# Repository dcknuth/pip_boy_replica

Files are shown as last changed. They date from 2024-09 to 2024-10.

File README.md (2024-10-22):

# Pip-Boy Replica
Making a Pip-Boy replica. Will not exactly match any given model from the game or episodes, but is inspired by them

[Video of the final product](https://youtu.be/MKkzPV8Xsxo)
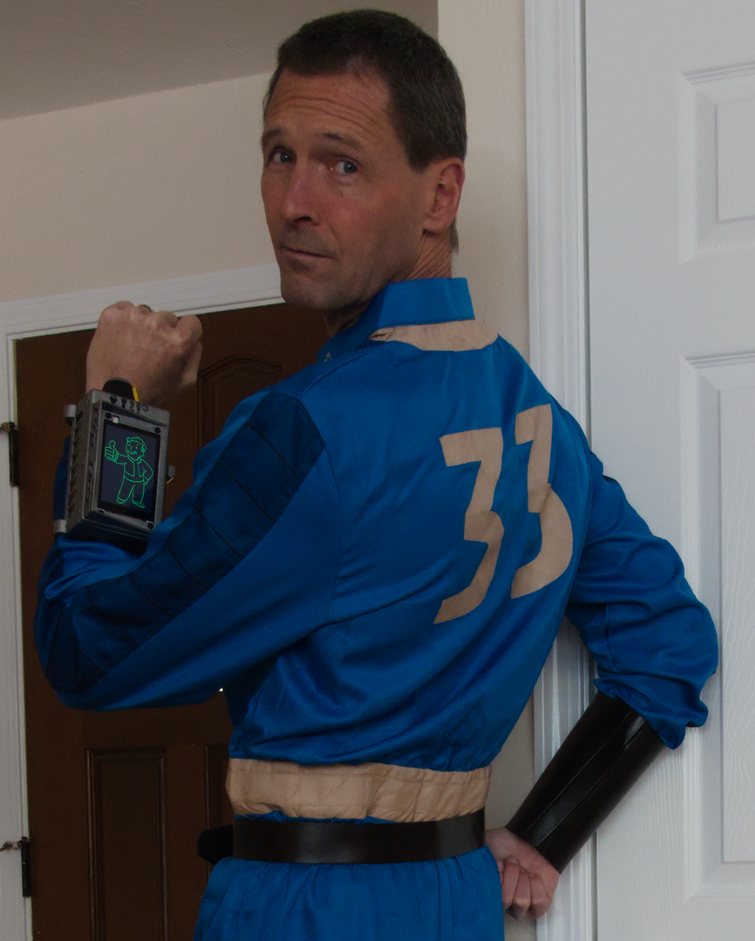
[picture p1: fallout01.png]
Showing Fallout Boy mode

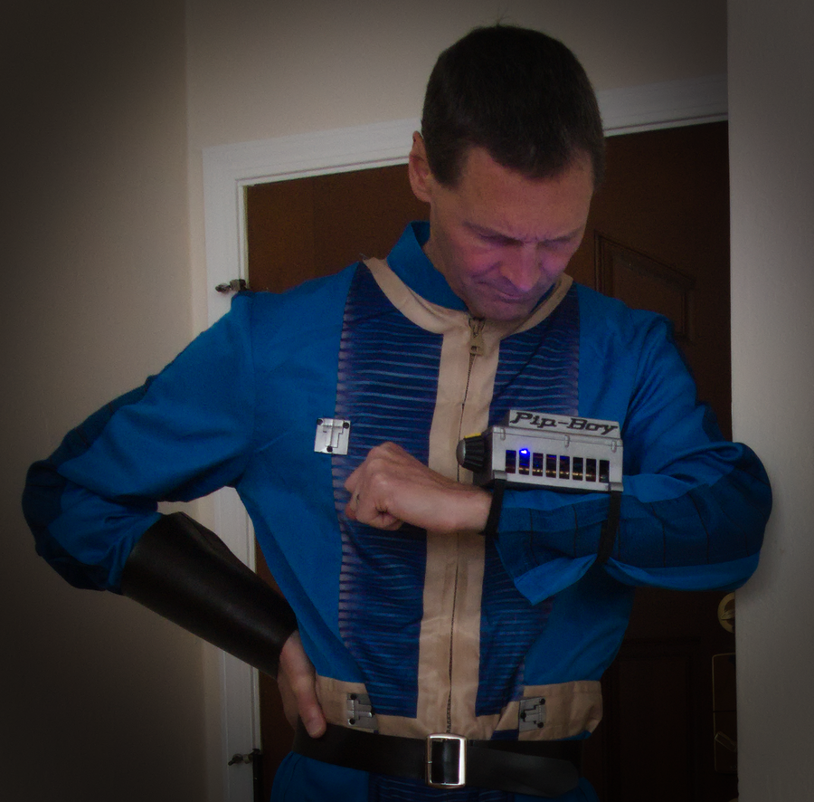
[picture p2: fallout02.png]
View of the front with flashlight mode on

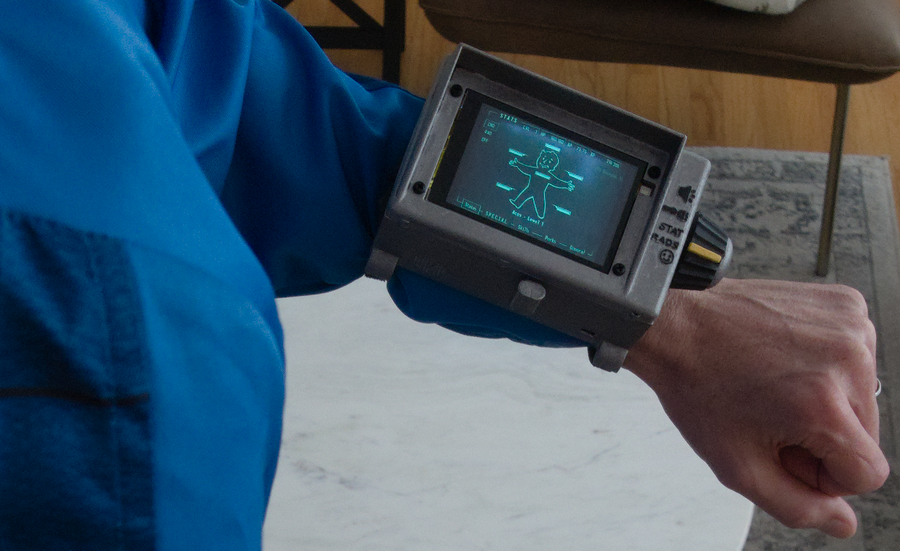
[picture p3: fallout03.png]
View of the top showing status mode


## Function List
These are the functions that we will try to add to our Pip-Boy with a bit of discussion on how and why
* Fallout Boy - Just a picture of the "thumbs up" fallout boy image. Recognizable from a distance and was a big plot item for the Amazon Fallout series in addition to being common in the games
* Geiger Counter - A real, working one based on data passed from a [MightyOhm Geiger Counter DIY kit](https://mightyohm.com/blog/products/geiger-counter/). I think I bought mine through [AdaFruit](https://www.adafruit.com/product/483)
* Status Indicator - Just a static screen borrowed from the Fallout 3 video game
* Flashlight - Will just turn on the screen to white and the front-facing LED of this particular board to ~90%. Might even be useful Halloween night?
* Radio - Will play "I Don't Want to Set the World on Fire", which was the intro song to the Fallout 3 video game and was in the Amazon series. The screen will show a static radio mode image from the game

## The Case
The case is 3D printed and will be in four parts:
* A bottom that the Geiger counter can be screwed into. It will additionally house:
  - Cutouts to the Geiger-Muller tube. For better reading, but mostly so you can just see it's there
  - Power switch for the Geiger counter and one for the screen/system
  - Hole and key for the rotary encoder board
  - Speaker grills for the beeper on the Geiger counter and for the speaker from the main board
  - Hole for a USB-C connector. This will charge the battery, not program the ESP32
  - Holes to hold small magnets to secure the top to the bottom
* A case top with the following:
  - Hole for the screen and LED. Also a recess for the unused ambient light sensor
  - A hood, mostly for aesthetic reasons. It's there in the game and other replicas and will give us a place to put some lettering that is visible
  - Indicator markings for what mode we are in
  - Holes for the small magnets to hold the top and bottom together
* A knob, to select the mode we are in. It will pressure fit to the rotary encoder shaft
* A pocket for the lithium polymer battery. It will be combined with a AAA blank so it can go where a AAA would be placed in the Geiger counter. This should keep it from moving around inside the case and damaging the Geiger tube.

All the OpenSCAD models are in the [3d_models](https://github.com/dcknuth/pip_boy_replica/3d_models) directory. There are a few extras that are needed modules or might be helpful

## Parts List
Will fill this in as the project progresses
* [Display with ESP32 - ESP32-3248S035](https://www.amazon.com/gp/product/B0C4KSKW96)
* [MightyOhm Geiger Counter](https://www.adafruit.com/product/483)
* Small speaker - I salvaged mine from some old device that I no longer remember
* [Rotary encoder](https://www.amazon.com/gp/product/B07B68H6R8) - to switch between modes. A custom knob will go on top of this
* 3D printer, I will not link, but I have an Ender3 that is a couple years old
* I used [this filament](https://www.amazon.com/gp/product/B00MEZEEJ2/), but most PLA should be fine. This is a color that would be forgiving if it shows through
* [Step up and charge controller board](https://www.amazon.com/gp/product/B09YD5C9QC/?th=1) This will get you the 5 volts you need to power the ESP32 board above from the lithium polymer battery below
* [Lipo battery](https://www.amazon.com/gp/product/B098DSP8YC/) Can power both the ESP32 board and the Geiger counter for some time and will still fit inside the case (smaller than the Geiger counter length)
* [Buck down](https://www.amazon.com/gp/product/B07T7L51ZW/) Converter to go from 5v to the 3v the Geiger counter wants
* [Jumper kit](https://www.amazon.com/gp/product/B08RMQP6YP/) To make jumper cables for the power switches and to hook things up in a way that can be disassembled easily
* [4-40 screws](https://www.amazon.com/gp/product/B0BNN7YRX8/) These are a good size to keep the Geiger attached to the bottom of the case with threads that are just big enough to 3D print a female side to the mount pads. I used the shortest 3/16 length
* [USB-C right angle](https://www.amazon.com/gp/product/B0B2NJ3P3L/) This allowed a friction fit to hold the step-up/charger board to the side of the case and to plug/unplug a charging cable without having to stress the PipBoy too much
* Small SD card. Any <= 4G should work. After some trouble that was not the fault of my first card, I bought [these](https://www.amazon.com/gp/product/B0D2SW1BLR/?th=1) They work
* Some [black nylon screws](https://www.amazon.com/gp/product/B0BNB1K5P2/) and nuts to hold the screen to the top part of the box
* Some [super glue](https://www.amazon.com/gp/product/B0041GVBBG/) To glue in the magnets
* I used the smallest of [these magnets](https://www.amazon.com/gp/product/B0CW65QR14/) You can look at the size of the holes that they go in to double check sizing
* I already had some hook and loop cable manager on hand, [like this](https://www.amazon.com/Xnakko-Double-Fastening-Reusable-Manager/dp/B095PNTVJ4/) to go through the lugs at the corners of the lower case and hold it to your forearm
* [This](https://www.amazon.com/gp/product/B07N6HFBRX/) smoothed out the 3D prints with some acetone to dilute it to make it easier to work with
* Then [this](https://www.amazon.com/Rust-Oleum-Automotive-260510-12-Ounce-Sandable/dp/B006ZLQ4HQ/) to prime and finish filling in the parts
* To paint the raised lettering I used [acrylic pens](https://www.amazon.com/gp/product/B0BKP1M6QK/?th=1)
* I borrowed my daughter's acrylic paints and brushes to do non-spray parts (I got her some additional to even things up)
* Most parts were finished with [this pounded pewter spray paint](https://www.homedepot.com/p/BEHR-PREMIUM-12-oz-SP-303-Antique-Pewter-Gloss-Interior-Exterior-Hammered-Spray-Paint-Aerosol-B061344/319367935) I don't know if I super-love this, but it worked
* You will need a variety of sandpaper

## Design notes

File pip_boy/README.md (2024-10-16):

# Platformio Project for Pip-Boy Replica
This is the code part for the ESP32-3248S035 that is the screen of the replica and drives most of the functionality

## Warnings
* TJpg_Decoder cannot handle progressively encoded jpegs. It will find the file, but report 0 width and height and not display
* Some of the options to libraries used seem to have to be passed in as compiler flags to make it to the compiling of the parts of the libraries. This is why there are a bunch of "-D" flags in the platformio.ini file. This can cause confusion with descriptions/instructions using the Arduino IDE which don't seem to need this
* Also a difference, PlatformIO wants proper function declarations or definitions prior to using them, which Arduino often does not need, so I move those up front or declare them as needed

## Overview
There are five modes to the device that are each pretty simple on their own and I use a rotary encoder library to help switch between the modes. Each of the modes might have three pieces:
1. Definitions or declarations in the pip_boy_config.h file or at the top of the main.cpp file. I have tried to keep them all there and this includes functions needed
2. Setup is mostly in the main setup function as it is supposed to be
3. The loop in main is setup to first change between the modes in response to a move of the rotary encoder and then to keep any current background tasks running for the mode in use

The modes are:
### Fallout Boy
This just displays an image of Fallout Boy in Portrait so that if you are holding the PipBoy on the left hand up, he shows in the proper way. All the images come off of the SD card as the modes switches via the TJpg_Decoder library. This image is the only one that needs to be rotated 90 degrees clockwise before being stored to the card
### Geiger Counter
This will display a speedometer-like gauge where the needle should point at the current count from the geiger counter. The geiger counter sends this out over its serial connection every second and we try to pull characters from this one-by-one every time through the event loop. This is done via this EspSoftwareSerial library. When we get to the end of a line, the count for that second is updated and the needle for the gauge is moved when a change in that value is detected. There is a pound define to just keep bouncing the value from 0 to 100 as background radiation seems to average a bit under 1. You have to hold a source very close to the tube to get more than three counts in a second. A log (or adaptive) scale might be better, but is left as an exercise for the reader. The count goes to zero if the geiger counter is starting or something weird happens to the serial line (as a natural part of trying to parse and read the input). This should be fine and things will fix themselves when the updates start or the next line comes in. The updating of the needle is done with the TFT_eSPI library and two sprites.
### Status
Just displays a static, status image from the in-game PipBoy in proper landscape orientation
### Flashlight
Sets the screen to white and turns on the front facing LED at a high brightness. Interesting and the particular board I used had the LED on the front, but probably not great as an actual flashlight. Matches a function of the PipBoy in the games though
### Radio
Displays a static radio image from the games and plays a version of the intro song to Fallout 3 via the ESP8266Audio library

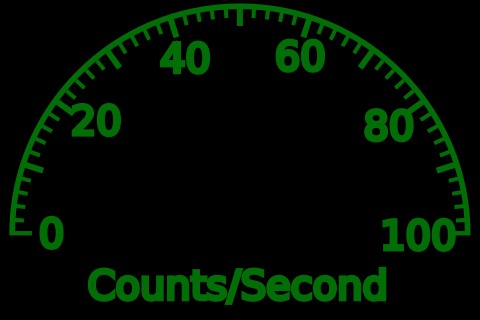
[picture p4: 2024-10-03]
sd_card_images/rads_dial.jpg

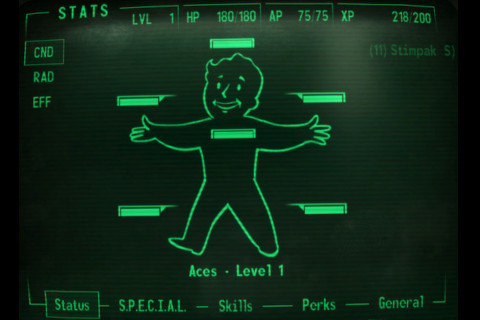
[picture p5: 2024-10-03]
sd_card_images/status_480x320.jpg

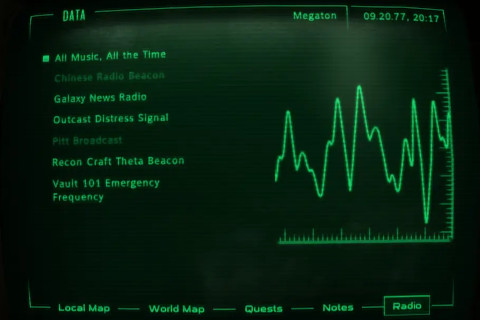
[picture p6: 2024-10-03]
sd_card_images/radio480x320.jpg

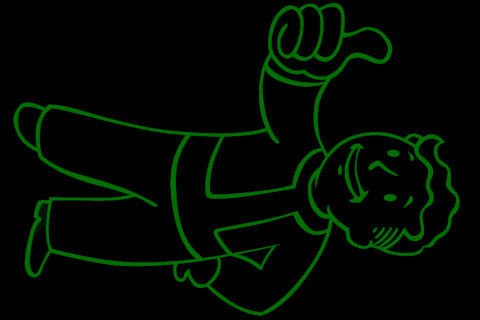
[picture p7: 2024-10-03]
sd_card_images/fallout-boy480x320.jpg

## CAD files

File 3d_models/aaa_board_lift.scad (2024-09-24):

// aaa blank with a handle on it to set a board into a tight box
$fn = 100;
use <aaa_battery.scad>;
body_l = 42.8;
aaa_d = 10.4;
wall = 1.6;

union() {
  aaaBattery(body_l=body_l, pos_button_h=0.8);
  hull() {
    translate([aaa_d/2-wall, 0, wall])
      rotate([90, 0, 0])
        cylinder(h=wall, d=wall, center=true);
    translate([body_l/2.5, 0, body_l/2])
      rotate([90, 0, 0])
        cylinder(h=wall, d=wall, center=true);
    translate([aaa_d/2-wall, 0, body_l-wall])
      rotate([90, 0, 0])
        cylinder(h=wall, d=wall, center=true);
  }
}

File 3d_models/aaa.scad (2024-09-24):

use <aaa_battery.scad>;

aaaBattery();

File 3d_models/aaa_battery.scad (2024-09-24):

// AAA battery (designed to stay put in a normal holder)
// Some of the measurements are slightly diffent than specification
//  to print at the right size or to better hold in the holder that
//  I happen to have. You can pass in whatever you need
$fn = 100;

module batteryNoRing(d=10.4, body_l=43.1, pos_button_d=3.6,
                  pos_button_h=1.0, pos_nub_d=1.2, pos_nub=true) {
  nub_h = 1.0;
  union() {
    cylinder(h=body_l, d=d);
    // positive terminal button
    translate([0, 0, body_l])
      cylinder(h=pos_button_h, d1=pos_button_d+0.2, d2=pos_button_d);
    if (pos_nub) {
      translate([0, 0, body_l+pos_button_h])
        cylinder(h=nub_h, d1=pos_nub_d+0.2, d2=pos_nub_d-0.2);
    }
  }
}

module aaaBattery(d=10.4, body_l=43.1, pos_button_d=3.6,
                  pos_button_h=1.0, pos_nub_d=1.2, pos_nub=true,
                  neg_ring_d=1.7, neg_ring_outer=5.5, neg_ring=true) {
  if (neg_ring) {
    difference() {
      batteryNoRing(d=d, body_l=body_l, pos_button_d=pos_button_d,
                    pos_button_h=pos_button_h, pos_nub_d=pos_nub_d,
                    pos_nub=pos_nub);
      // ring for first spring coil to sit in
      rotate_extrude(convexity = 10)
        translate([neg_ring_outer/2, 0, 0])
          circle(r=neg_ring_d/2);
    }
  }
  else {
    batteryNoRing(d=d, body_l=body_l, pos_button_d=pos_button_d,
                  pos_button_h=pos_button_h, pos_nub_d=pos_nub_d,
                  pos_nub=pos_nub);
  }
}

// test set
my_offset = 20;
aaaBattery();
translate([-my_offset, 0, 0])
  aaaBattery(neg_ring=false);
translate([my_offset, 0, 0])
  aaaBattery(pos_nub=false, neg_ring=false);
// AA
translate([0, my_offset, 0])
  aaaBattery(d=14.1, body_l=48.6, pos_button_d=5.1,
              pos_button_h=1.4, pos_nub_d=1.2, pos_nub=false,
              neg_ring_d=1.3, neg_ring_outer=5.9, neg_ring=false);

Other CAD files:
3d_models/aaa_lipo_mount.scad
3d_models/attach.scad
3d_models/case_top.scad
3d_models/magnet_holder_tiny.scad
3d_models/pb_case_lower.scad
3d_models/pb_knob_w_hole.scad
3d_models/pb_letters.scad
3d_models/pip_boy_knob.scad
3d_models/pipboy_hood.scad
3d_models/screw_guide.scad
3d_models/speaker_grid.scad
3d_models/speaker_holder.scad
3d_models/test_lipo_mount.scad

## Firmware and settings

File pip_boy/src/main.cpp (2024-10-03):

#include <Arduino.h>
#include <WiFi.h>
#include <TJpg_Decoder.h>
#include <ESP32RotaryEncoder.h>
#include <SoftwareSerial.h>
#include "AudioFileSourceSD.h"
#include "AudioFileSourceID3.h"
#include "AudioGeneratorMP3.h"
#include "AudioOutputI2S.h"
#include "pip_boy_config.h"
// images
#define FS_NO_GLOBALS
#include <FS.h>
#ifdef ESP32
  #include "SPIFFS.h" // ESP32 only
#endif
#define SD_CS   5
// Include the TFT library https://github.com/Bodmer/TFT_eSPI
#include "SPI.h"
#include <TFT_eSPI.h> 
TFT_eSPI tft = TFT_eSPI();
TFT_eSprite back = TFT_eSprite(&tft); // background for geiger needle
TFT_eSprite needle = TFT_eSprite(&tft); // geiger needle

// Gieger serial port RX(our esp32 GPIO)
//  TX (33 listed, but no TX needed receive only)
SoftwareSerial SWSerial(GeigerSerial, 33);

// rotary encoder
RotaryEncoder rotaryEncoder(rotary_encoder_CLK_pin, rotary_encoder_DT_pin);
void knobCallback(long value) {
    // This gets executed every time the knob is turned
    if (PB_DEBUG) {
      Serial.printf( "Value: %i\n", value );
    }
    PipBoy_mode = value;
}

// audio
AudioFileSourceSD *play_file;
AudioGeneratorMP3 *mp3;
AudioOutputI2S *audio_out;
AudioFileSourceID3 *id3;
SPIClass SDSPI(VSPI);

// draw
bool tft_output(int16_t x, int16_t y, uint16_t w, uint16_t h, uint16_t* bitmap) {
  // Stop further decoding as image is running off bottom of screen
  if ( y >= tft.height() ) return 0;
  // This function will clip the image block rendering automatically at the TFT boundaries
  tft.pushImage(x, y, w, h, bitmap);
  return 1;
}
bool needle_output(int16_t x, int16_t y, uint16_t w, uint16_t h, uint16_t* bitmap) {
  // Stop further decoding as image is running off bottom of screen
  if ( y >= needle.height() ) return 0;
  // This function will clip the image block rendering automatically at the TFT boundaries
  needle.pushImage(x, y, w, h, bitmap);
  return 1;
}

void startPlayback() {
  if (!mp3) {
    play_file = new AudioFileSourceSD(MP3_FILENAME);
    id3 = new AudioFileSourceID3(play_file);
    audio_out = new AudioOutputI2S(0, 2, 8, -1); // Output to builtInDAC
    audio_out->SetOutputModeMono(true);
    audio_out->SetGain(1.0);
    mp3 = new AudioGeneratorMP3();
    mp3->begin(id3, audio_out);
  }
}

void stopPlayback() {
  if (mp3) {
    mp3->stop();
    delete mp3;
    mp3 = NULL;
  }
  if (id3) {
    id3->close();
    delete id3;
    id3 = NULL;
  }
  if (audio_out) {
    audio_out->stop();
    delete audio_out;
    audio_out = NULL;
  }
  if (play_file) {
    play_file->close();
    delete play_file;
    play_file = NULL;
  }
  if (PB_DEBUG) {
    Serial.println("Stopped music and cleaned up");
  }
}

void ledOff(void) {
  digitalWrite(4, 1.0);
  digitalWrite(16, 1.0);
  digitalWrite(17, 1.0);
}

void getGeiger() {
  if (SWSerial.available()) {
    geigerData = (SWSerial.read());
    geigerSerial += char(geigerData);
  }
}
void processGeiger() {
  if (geigerData == 0x0D) {  // \r CR detected
    // Parse CPS, CPM, and uS/hr from the string
    int comma1Index = geigerSerial.indexOf(',');
    int comma2Index = geigerSerial.indexOf(',', comma1Index + 1);
    int comma3Index = geigerSerial.indexOf(',', comma2Index + 1);
    int comma4Index = geigerSerial.indexOf(',', comma3Index + 1);
    int comma5Index = geigerSerial.indexOf(',', comma4Index + 1);
    int comma6Index = geigerSerial.indexOf(',', comma5Index + 1);
    String cpsString = geigerSerial.substring(comma1Index + 1, comma2Index);
    String cpmString = geigerSerial.substring(comma3Index + 1, comma4Index);
    String sievertsString = geigerSerial.substring(comma5Index + 1, comma6Index);
    if (cpsString != "") {
      Rad_Last = Rad_Count;
      Rad_Count = cpsString.toInt();
      newGeigerVals = true;
    }
    // cpm = cpmString.toInt();
    // sieverts = sievertsString.toFloat();
    // svyear = (sieverts * 8.76);
    geigerSerial = "";  // Clear the string for next time
  }
}
void updateGeigerCount(void) {
  if (GEIGER == false) {
    if (Rad_Up == true && Rad_Count < 100) {
      Rad_Count++;
    } else if (Rad_Up == false && Rad_Count > 0) {
      Rad_Count--;
    } else if (Rad_Up == true && Rad_Count > 99) {
      Rad_Count = 99;
      Rad_Up = false;
    } else {
      Rad_Count = 1;
      Rad_Up = true;
    }
  } else {
    getGeiger();       // Grab MightyOhm serial data
    processGeiger();   // Extract data and process
  }
}

void paintNeedle(int count) {
  float angle = count * 1.8;
  // if (PB_DEBUG) {
  //       Serial.printf("We are in paint needle with count %d and angle %f\n", count, angle);
  // }
  back.fillSprite(TFT_BLACK);
  needle.pushRotated(&back, angle, TFT_BLACK);
  back.pushSprite(129, 121);
}

void setup() {
  Serial.begin(115200);
  WiFi.mode(WIFI_OFF);
  Serial.begin(115200);
  SWSerial.begin(9600);

  // led setup
  pinMode(4, OUTPUT);
  pinMode(17, OUTPUT);
  pinMode(16, OUTPUT);
  ledOff();

  // Initialise the TFT
  tft.begin();
  tft.setRotation(3);
  tft.fillScreen(TFT_BLACK);
  tft.setSwapBytes(true); // We need to swap the colour bytes (endianess)

  // SD setup (needs to be after tft for esp32)
  pinMode(5, OUTPUT);
  digitalWrite(5, HIGH);
  SDSPI.begin(18, 19, 23); // SDSPI.begin(SCLK, MISO, MOSI);
  SDSPI.setFrequency(1000000);
  if (!SD.begin(5, SDSPI)) {
    Serial.println(F("SD.begin failed!"));
    while (1) delay(0);
  }
  
  // The jpeg image can be scaled by a factor of 1, 2, 4, or 8
  TJpgDec.setJpgScale(1);
  // The decoder must be given the exact name of the rendering function above
  TJpgDec.setCallback(needle_output);
  if (needle.createSprite(211, 21) == nullptr && PB_DEBUG) {
    Serial.println("Needle sprite NOT created, insufficient RAM!");
  }
  needle.setSwapBytes(true);
  TJpgDec.drawSdJpg(0, 0, GEIGER_NEEDLE);
  // back to writing to the tft
  TJpgDec.setCallback(tft_output);
  // create the needle background sprite
  if (back.createSprite(211, 117) == nullptr && PB_DEBUG) {
    Serial.println("Background sprite NOT created, insufficient RAM!");
  }
  back.fillScreen(TFT_BLACK);
  back.setPivot(105, 105);

  // This tells the library that the rotary encoder has its own pull-up resistors
  rotaryEncoder.setEncoderType( EncoderType::HAS_PULLUP );
  // we have 5 modes, do not wrap around
  rotaryEncoder.setBoundaries(PB_MinMode, PB_MaxMode, false);
  rotaryEncoder.onTurned(&knobCallback);
  rotaryEncoder.begin();

  // LED should start off
  ledOff();
}

void loop() {
  int status = -1;
  // check for mode change
  if (PipBoy_mode != PipBoy_mode_prev) {
    if (PB_DEBUG) {
      Serial.printf("New mode is %d\n", PipBoy_mode);
    }
    // handle fallout-boy mode (default start position)
    if (PipBoy_mode == PB_FALLOUT_BOY) {
      if (PB_DEBUG) {
        Serial.printf("We are in the PB_FALLOUT_BOY section\n");
      }
      if (PB_DEBUG) {
        uint16_t w = 0, h = 0;
        TJpgDec.getSdJpgSize(&w, &h, FALLOUT_BOY);
        Serial.printf("%s width is %d and height is %d\n", FALLOUT_BOY, w, h);
      }
      // Draw the image at 0,0
      status = TJpgDec.drawSdJpg(0, 0, FALLOUT_BOY);
      if (PB_DEBUG) {
        Serial.printf("Exiting change to PB_FALLOUT_BOY\n");
      }
    }
    // handle geiger counter mode
    if (PipBoy_mode == PB_GEIGER) {
      if (PB_DEBUG) {
        Serial.printf("We are in the PB_GEIGER section\n");
      }
      status = TJpgDec.drawSdJpg(0, 0, GEIGER_BG);
      // paint the indicator/needle
      paintNeedle(Rad_Count);
    }
    // handle status mode
    if (PipBoy_mode == PB_SHOW_STATUS) {
      if (PB_DEBUG) {
        Serial.printf("We are in the PB_SHOW_STATUS section\n");
      }
      if (PB_DEBUG) {
        uint16_t w = 0, h = 0;
        TJpgDec.getSdJpgSize(&w, &h, SHOW_STATUS);
        Serial.printf("%s width is %d and height is %d\n", SHOW_STATUS, w, h);
      }
      // Draw the image at 0,0
      status = TJpgDec.drawSdJpg(0, 0, SHOW_STATUS);
      if (PB_DEBUG) {
        Serial.printf("Exiting change to PB_SHOW_STATUS with status %d\n", status);
      }
    }
    // handle flashlight mode
    if (PipBoy_mode == PB_FLASHLIGHT) {
      if (PB_DEBUG) {
        Serial.printf("We are in the PB_FLASHLIGHT section\n");
      }
      tft.fillScreen(TFT_WHITE);
      digitalWrite(4, 0.1);
      digitalWrite(16, 0.1);
      digitalWrite(17, 0.1);
      if (PB_DEBUG) {
        Serial.printf("Exiting change to PB_FLASHLIGHT with status %d\n", status);
      }
    } else if (PipBoy_mode != PB_FLASHLIGHT && PipBoy_mode_prev == PB_FLASHLIGHT) {
      ledOff();
    }
    // handle radio mode
    if (PipBoy_mode == PB_RADIO) {
      TJpgDec.drawSdJpg(0, 0, RADIO_JPG);
      startPlayback();
      mp3->loop();
    }
    else if(PipBoy_mode != PB_RADIO && PipBoy_mode_prev == PB_RADIO) {
      stopPlayback();
    }
    PipBoy_mode_prev = PipBoy_mode;
  }
  // mode has not changed, handle things that need updates
  else if (PipBoy_mode == PB_RADIO) {
      mp3->loop();
  } else if (PipBoy_mode == PB_GEIGER) {
    if (Rad_Count != Rad_Last) {
      paintNeedle(Rad_Count);
      Rad_Last = Rad_Count;
    }
  }
  // always look for new geiger values
  updateGeigerCount();
  if (newGeigerVals && PB_DEBUG) {
    Serial.print("CPS: ");
    Serial.println(Rad_Count);
    newGeigerVals = false;
  }
}

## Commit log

2024-09-07 rotary encoder and radio
    Only the mode selection and playing music is done here
2024-09-24 3d models
    In progress 3d models and images needed for some of the modes
    [aaa.scad, aaa_battery.scad, aaa_board_lift.scad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]
2024-10-03 all five modes
    All five pipboy modes working and updates to some of the 3D models
    [aaa_lipo_mount.scad, case_top.scad, pb_case_lower.scad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]
